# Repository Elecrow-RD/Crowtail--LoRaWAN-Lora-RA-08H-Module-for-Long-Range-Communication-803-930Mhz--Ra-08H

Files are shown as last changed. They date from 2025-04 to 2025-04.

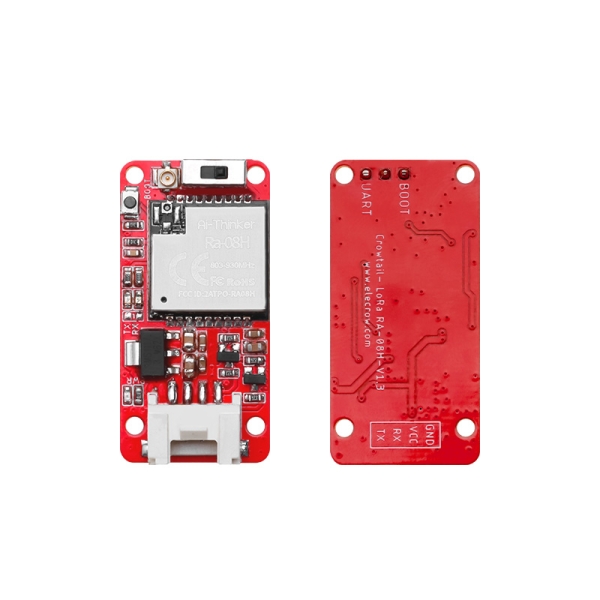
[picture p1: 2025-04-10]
crt01158h-crowtail6.jpg

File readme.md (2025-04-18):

### 1, Product picture

crt01158h-crowtail6

### 2, Product version number

| | Hardware | Software | Remark |
| ---- | --- | --- | --- |
| 1 | V1.0 | V1.0 | latest |

### 3, product information

#### Display Module Specifications

- Voltage: 3.3~5V
- Theoretical maximum transmission power+22dBm
- Supported frequency band: 803~930MHZ
- High sensitivity: -138dBm@125KzSF12
- Support spread spectrum factor: SF5/SF6/SF7/SF8/SF9/SF10/SF11/SF12
- Embedded memory: 128KB FLASH, 16KB SRAM
- Support LoRa/(G) FSK/BPSK/(G) MSK modulation
- Maximum transmission distance 1KM (ideal value for open space)
- With download and communication switching functions, users can customize programming
- Configure the first-generation IPEX seat
- Dimension (mm): 40 (L) * 20 (W) * 7.5 (H)

### 

### 4,Quick Start

##### Arduino IDE starts

STEP1 Configure controller board&communication port
On top of the Arduino IDE, click “Tools>Board>” and select “Arduino Uno” from the available options
SELECT BOARD.png
STEP2 Select the COM port that indicates Arduino Uno. Please note that the actual numbers after the “COM” word will vary from computer to computer, so they could be different from the ones shown in the figure.
S 2 2.png

### 6,Folder structure.

|--Datasheet: Includes datasheets for components used in the project, providing detailed specifications, electrical characteristics, and pin configurations.

|--Eagle_SCH&PCB: Contains **Eagle CAD** schematic (`.sch`) and PCB layout (`.brd`) files. These are used for circuit design and PCB manufacturing.

|--example: Provides example code and projects to demonstrate how to use the hardware and libraries. These examples help users get started quickly.

|--factory_firmware: Stores pre-compiled factory firmware that can be directly flashed onto the device. This ensures the device runs the default functionality.

### 7,Pin definition

// Pin2——>LORA-TXD

// Pin3——>LORA-RXD

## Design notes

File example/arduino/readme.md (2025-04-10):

**Arduino**: This folder contains sample programs for the Arduino platform, which is known for its ease of use and versatility in creating interactive electronic projects.

#### NOTE!!!:When running this program , you need to download the officially provided libraries and place them in the libraries of arduino. esp32 version needs to be 2.0.10 the version of the libraries is the same as the officially provided version.

Link to the corresponding course wiki:

Video Tutorial Links：https://www.youtube.com/watch?v=smDFHRxDYdw

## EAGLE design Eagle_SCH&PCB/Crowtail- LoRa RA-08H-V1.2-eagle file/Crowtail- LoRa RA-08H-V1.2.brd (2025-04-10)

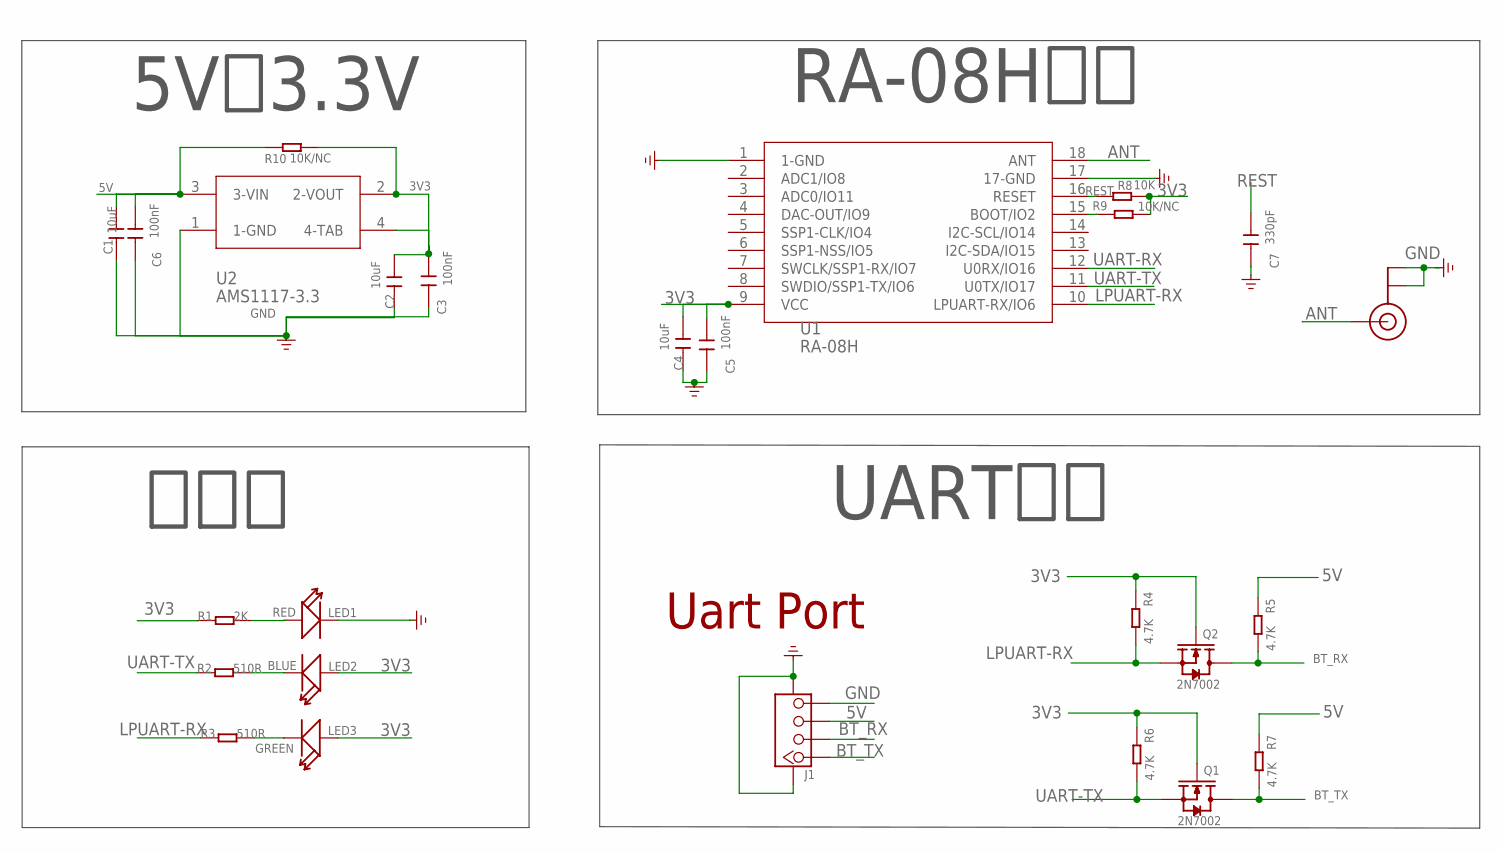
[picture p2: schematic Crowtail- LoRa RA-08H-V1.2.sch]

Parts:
C1, C2, C4: 10uF; C0805
C3, C5, C6: 100nF; C0603
C7: 330pF; C0603
J1: TWIG-4P-2.0-SMD-FEMALE-REINFORCE'90D'; 4P-SMD-2.0-90D
J2: U.FL
LED1: RED; LED-0603
LED2: BLUE; LED-0603
LED3: GREEN; LED-0603
Q1, Q2: 2N7002; SOT23
R1: 2K; 0603
R2, R3: 510R; 0603
R4, R5, R6, R7: 4.7K; DISCRETE_R0603
R8: 10K; DISCRETE_R0603
R9, R10: 10K/NC; DISCRETE_R0603
U1: RA-08H; RA-08H-SMD-18
U2: AMS1117-3.3; AMS1117-3.3-SOT223

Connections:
3V3: C2.2, C3.2, C4.2, C5.2, LED2.+, LED3.+, Q1.1 (G), Q2.1 (G), R1.1, R4.1, R6.1, R8.2, R9.2, R10.2, U1.9 (VCC), U2.2 (2-VOUT), U2.4 (4-TAB)
5V: C1.2, C6.2, J1.3, R5.1, R7.1, R10.1, U2.3 (3-VIN)
ANT: J2.P$3 (SIGNAL), U1.18 (ANT)
BT_RX: J1.2, Q2.3 (D), R5.2
BT_TX: J1.1, Q1.3 (D), R7.2
GND: C1.1, C2.1, C3.1, C4.1, C5.1, C6.1, C7.1, J1.4, J1.SS1, J1.SS2, J2.P$1 (GND), J2.P$2 (GND), LED1.-, U1.1 (1-GND), U1.17 (17-GND), U2.1 (1-GND)
LPUART-RX: Q2.2 (S), R3.1, R4.2, U1.10 (LPUART-RX/IO6)
unnamed: LED2.-, R2.2
unnamed: LED1.+, R1.2
unnamed: LED3.-, R3.2
unnamed: R9.1, U1.15 (BOOT/IO2)
REST: C7.2, R8.1, U1.16 (RESET)
UART-RX: U1.12 (U0RX/IO16)
UART-TX: Q1.2 (S), R2.1, R6.2, U1.11 (U0TX/IO17)

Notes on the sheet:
Uart Port
指示灯
5V转3.3V
RA-08H主控
UART串口

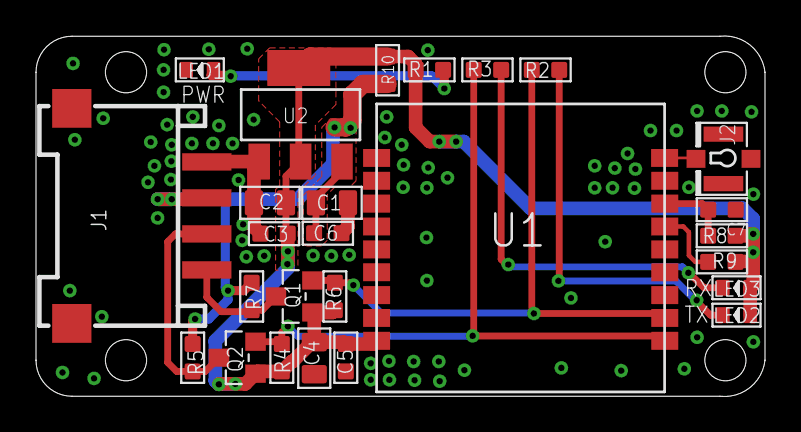
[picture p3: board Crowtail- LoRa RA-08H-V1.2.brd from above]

Board: 2 copper layers, 40.5 x 20.0 mm, 26 parts (0 on the bottom side), 13 nets.

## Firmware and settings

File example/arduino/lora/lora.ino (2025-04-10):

#include <SoftwareSerial.h> 
// Pin2——>LORA-TXD
// Pin3——>LORA-RXD
SoftwareSerial LORA(2, 3); 
char val;
 
void setup() {
  Serial.begin(9600); 
  Serial.println("LORA is ready!");
  LORA.begin(9600);
}
 
void loop() {
  if (Serial.available()) {
    val = Serial.read();
    LORA.print(val);
    delay(10);
  }
 
  if (LORA.available()) {
    val = LORA.read();
    Serial.print(val);
    delay(10);
  }
}
